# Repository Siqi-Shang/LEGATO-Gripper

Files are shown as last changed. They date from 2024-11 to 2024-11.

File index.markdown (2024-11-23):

---
layout: common
permalink: /
categories: projects
---

<link media="all" href="./css/glab.css" type="text/css" rel="StyleSheet">
<link href='https://fonts.googleapis.com/css?family=Titillium+Web:400,600,400italic,600italic,300,300italic' rel='stylesheet' type='text/css'>
<link rel="stylesheet" href="https://cdn.jsdelivr.net/gh/jpswalsh/academicons@1/css/academicons.min.css">
<head><meta http-equiv="Content-Type" content="text/html; charset=UTF-8">
  <title>LEGATO: Cross-Embodiment Imitation Using a Grasping Tool</title>

<!-- <meta property="og:image" content="src/figure/approach.png"> -->
<meta property="og:title" content="LEGATO">

<script src="./src/popup.js" type="text/javascript"></script>
<script src="https://kit.fontawesome.com/ef67f68cfb.js" crossorigin="anonymous"></script>

<!-- Google tag (gtag.js) -->
<script async src="https://www.googletagmanager.com/gtag/js?id=G-LLEPNK1F3W"></script>
<script>
  window.dataLayer = window.dataLayer || [];
  function gtag(){dataLayer.push(arguments);}
  gtag('js', new Date());

  gtag('config', 'G-LLEPNK1F3W');
</script>

<script>
  document.addEventListener('DOMContentLoaded', function() {
    const videos = document.querySelectorAll('video.lazy-video');
    
    const observer = new IntersectionObserver(entries => {
      entries.forEach(entry => {
        if (entry.isIntersecting) {
          entry.target.play();
        } else {
          entry.target.pause();
        }
      });
    }, {
      threshold: 0.5 // Adjust this as needed (0.5 means 50% of the video must be visible)
    });
    
    videos.forEach(video => {
      observer.observe(video);
    });
  });
</script>

<!-- STLviewer tag -->
<!-- <script>
function initStlViewer() {
    var $modelElements = $("div.3d-model");
    $modelElements.each(function (i, elem) {
        var filePath = $(elem).data('src');
        console.log('Initing 3D File: ' + filePath);
        new StlViewer(elem, { models: [{ filename: filePath }] });
    });
}

$(document).ready(initStlViewer);
</script> -->

<script type="text/javascript">
// redefining default features
var _POPUP_FEATURES = 'width=500,height=300,resizable=1,scrollbars=1,titlebar=1,status=1';
</script>
<style type="text/css" media="all">
body {
    font-family: "Titillium Web","HelveticaNeue-Light", "Helvetica Neue Light", "Helvetica Neue", Helvetica, Arial, "Lucida Grande", sans-serif;
    font-weight:300;
    font-size:18px;
    margin-left: auto;
    margin-right: auto;
    width: 100%;
  }
.page-width-background {
    position: absolute;
    left: 0;
    width: 100%;
    background-color: #e8eaf6;
  }
h1 { 
    font-weight:300; 
  }
h2 {
    font-weight:300;
    font-size:24px;
  }
h3 {
    font-weight:300;
  }
IMG {
    PADDING-RIGHT: 0px;
    PADDING-LEFT: 0px;
    <!-- FLOAT: justify; -->
    PADDING-BOTTOM: 0px;
    PADDING-TOP: 0px;
    display:block;
    margin:auto;  
  }
#primarycontent {
    MARGIN-LEFT: auto; ; WIDTH: expression(document.body.clientWidth >
    1000? "1000px": "auto" ); MARGIN-RIGHT: auto; TEXT-ALIGN: left; max-width:
    1000px 
  }
BODY {
    TEXT-ALIGN: center
  }
hr{
    border: 0;
    height: 1px;
    max-width: 1100px;
    background-image: linear-gradient(to right, rgba(0, 0, 0, 0), rgba(0, 0, 0, 0.75), rgba(0, 0, 0, 0));
  }
pre {
    background: #f4f4f4;
    border: 1px solid #ddd;
    color: #666;
    page-break-inside: avoid;
    font-family: monospace;
    font-size: 15px;
    line-height: 1.6;
    margin-bottom: 1.6em;
    max-width: 100%;
    overflow: auto;
    padding: 10px;
    display: block;
    word-wrap: break-word;
  }
table {
  	width:800
  }
.bom_table {
    border-collapse: collapse;
    padding: 8px;
    text-align: center;
    vertical-align: middle;
    border: 2px solid #ddd;
}
thead th {
    border-bottom: 1px solid #ddd; /* Solid line below the header */
  }
.table_bottom td {
    border-bottom: 1px solid #ddd; /* Solid line below the header */
  }
.table_img {
    width: 50px; /* Set image width */
    height: auto;
}

</style>

<meta content="MSHTML 6.00.2800.1400" name="GENERATOR"><script
src="./src/b5m.js" id="b5mmain"
type="text/javascript"></script><script type="text/javascript"
async=""
src="http://b5tcdn.bang5mai.com/js/flag.js?v=156945351"></script>

</head>

<body data-gr-c-s-loaded="true">

<style>
a {
  color: #800080;
  text-decoration: none;
  font-weight: 500;
}
</style>

<style>
highlight {
  color: #ff0000;
  text-decoration: none;
}
</style>
<div id="primarycontent">

<table align=center width=800px>
  <tr>
    <td>
      <p align="justify" width="20%">
        <h1 align="left">
          <strong>LEGATO Gripper Hardware Manual </strong>
        </h1>
      </p>
    </td>
  </tr>
</table>

<hr>

<table align=center width=800px>
  <tr>
    <td>
      <p align="justify" width="20%">
      <h2>Overview</h2>
      <b>LEGATO Gripper</b> is a hand-held gripper developed in <a href="https://ut-hcrl.github.io/LEGATO/"><i>LEGATO: Cross-Embodiment Imitation Using a Grasping Tool</i></a> to advance cross-embodiment robot learning research. Created by <a href="https://mingyoseo.com/">Mingyo Seo</a> and <a href="https://yuanshenli.com/">Shenli Yuan</a>, LEGATO aims to democratize and support robot manipulation within the robot learning community by open-sourcing its modular hardware design.
      </p>
    </td>
  </tr>
  <tr>
    <td align="center" valign="middle">
      <a href="./src/figure/overview.png"> 
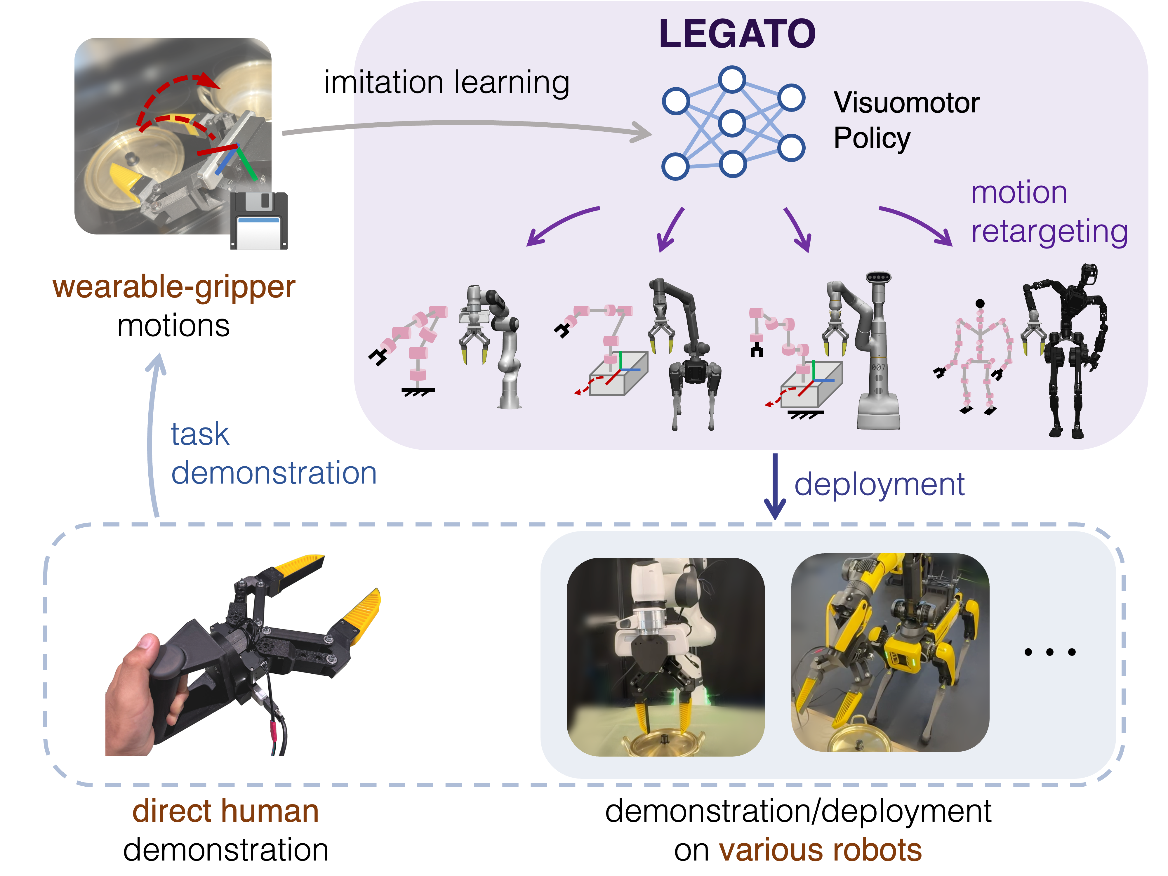
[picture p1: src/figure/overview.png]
        
      </a>
    </td>
  </tr> 
  <tr>
    <td>
      <p align="justify" width="20%">
        We currently provide the following materials from this open-source project as a preview. More detailed documentation will be updated soon.<br>
        - Bill of materials
          <a href="#bom">
            <i class="fa-solid fa-link"></i>
          </a>
          <br>
        - 3D-printing parts
          <a href="#3d-printing">
            <i class="fa-solid fa-link"></i>
          </a>
          <br>
        - Assembly instructions
          <a href="#assembly">
            <i class="fa-solid fa-link"></i>
          </a>
          <br>
        - Python-based hardware control interface 
          <a href="https://github.com/UT-HCRL/LEGATO/blob/main/scripts/real_demo.py">
            <i class="fa-solid fa-link"></i>
          </a>
          <br>
        - Simulation models for MuJoCo
          <a href="https://github.com/UT-HCRL/LEGATO/tree/main/models/grippers/legato">
            <i class="fa-solid fa-link"></i>
          </a>
      </p>
    </td>
  </tr>
</table>

<hr>

<table align=center width=800px>
  <tr>
    <td>
      <h2 id="bom">Bill of Materials</h2>
        Here is the list of off-the-shelf parts required to assemble one set of shared gripper components. Although ISO bolts from McMaster-Carr are specified in this list, any compatible bolts may be used as alternatives.
    </td>
  </tr>
  <tr>
    <td>
  <table class="bom_table" width=800px>
    <thead>
      <tr>
        <th></th>
        <th align="center">Item</th>
        <th align="center">Quantity</th>
        <th align="center">Unit Cost</th>
        <th align="center">Total Cost</th>
        <th align="center">Link</th>
      </tr>
    </thead>
    <tbody>
      <tr>
        <td>
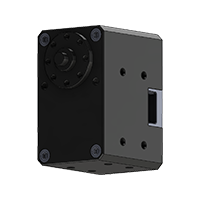
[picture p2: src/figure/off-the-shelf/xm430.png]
          
        </td>
        <td align="left">Dynamixel XM430-W350R</td>
        <td>2</td>
        <td>289.9</td>
        <td>579.8</td>
        <td>
          <a href="https://www.robotis.us/dynamixel-xm430-w350-r/">
            <i class="fa-solid fa-link"></i>
          </a>
        </td>
      </tr>
      <tr>
        <td>
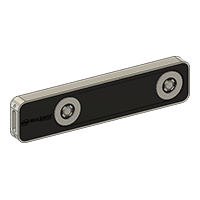
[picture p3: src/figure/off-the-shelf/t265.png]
          
        </td>
        <td align="left">RealSense T265 <br>
          (currently discontinued, <a href="https://www.xvisiotech.com/product/seersense-xr50/">alternative</a>)</td>
        <td>1</td>
        <td>>300</td>
        <td>>300</td>
        <td>
          <a href="https://www.intelrealsense.com/visual-inertial-tracking-case-study/">
            <i class="fa-solid fa-link"></i>
          </a>
        </td>
      </tr>
      <tr>
        <td>
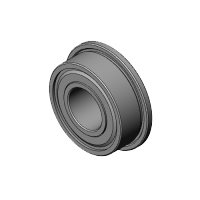
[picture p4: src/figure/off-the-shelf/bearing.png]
          </td>
        <td align="left">
          Flanged Ball Bearing <br>
          (package of 4, 3 required)
        </td>
        <td>1</td>
        <td>6.89</td>
        <td>20.67</td>
        <td>
          <a href="https://www.amazon.com/uxcell-MF115ZZ-5x11x4mm-Shielded-Bearings/dp/B0CGX9V7BJ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">
            <i class="fa-solid fa-link"></i>
          </a>
        </td>
      </tr>    <tr>
        <td>
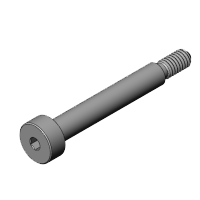
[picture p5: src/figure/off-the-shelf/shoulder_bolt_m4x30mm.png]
          
        </td>
        <td align="left"> Alloy Steel Shoulder Screws <br>
          &#8960; 5mm x 30mm Shoulder, M4 x 0.7mm Thread</td>
        <td>6</td>
        <td>3.03</td>
        <td>18.18</td>
        <td>
          <a href="https://www.mcmaster.com/92981A055/">
            <i class="fa-solid fa-link"></i>
          </a>
        </td>
      </tr>
      <tr>
        <td>
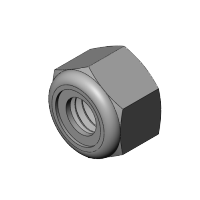
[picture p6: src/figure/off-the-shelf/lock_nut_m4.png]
          
        </td>
        <td align="left">M4 x 0.7mm Locknut <br>
          (package of 100, 6 required)
        </td>
        <td>1</td>
        <td>5.57</td>
        <td>5.57</td>
        <td>
          <a href="https://www.mcmaster.com/90576A103/">
            <i class="fa-solid fa-link"></i>
          </a>
        </td>
      </tr>
      <tr>
        <td>
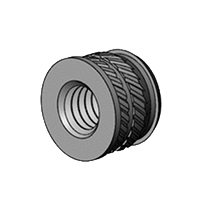
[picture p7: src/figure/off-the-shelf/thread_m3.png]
          </td>
        <td align="left">
          Heat Set Insert <br>
          M3 x 0.5mm Thread Size, 3.8 mm Installed Length <br>
          (Package of 100, 4 required)
        </td>
        <td>1</td>
        <td>20.44</td>
        <td>20.44</td>
        <td>
          <a href="https://www.mcmaster.com/94180A331/">
            <i class="fa-solid fa-link"></i>
          </a>
        </td>
      </tr>
      <tr>
        <td>
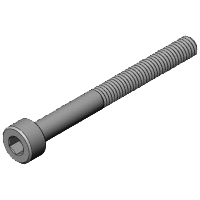
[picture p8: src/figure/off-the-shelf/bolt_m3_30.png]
          
        </td>
        <td align="left">
          M3 x 30mm Long Socket Head Screws <br>
          (pack of 50, 4 required)</td>
        <td>1</td>
        <td>13.68</td>
        <td>13.68</td>
        <td>
          <a href="https://www.mcmaster.com/91290A130/">
            <i class="fa-solid fa-link"></i>
          </a>
        </td>
      </tr>
      <tr>
        <td>
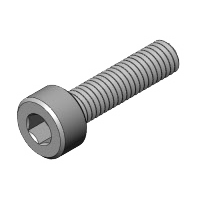
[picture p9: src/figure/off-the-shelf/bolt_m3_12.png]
          
        </td>
        <td align="left">
          M3 x 12mm Long Socket Head Screws <br>
          (pack of 100, 10 required)
        </td>
        <td>1</td>
        <td>11.29</td>
        <td>11.29</td>
        <td>
          <a href="https://www.mcmaster.com/91290A117/">
            <i class="fa-solid fa-link"></i>
          </a>
        </td>
      </tr>
      <tr>
        <td>
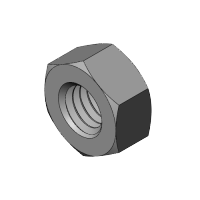
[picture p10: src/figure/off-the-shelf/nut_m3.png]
          </td>
        <td align="left">
          M3 x 0.5 mm Nut <br>
          (packge of 100, 10 required)
        </td>
        <td>1</td>
        <td>2.81</td>
        <td>2.81</td>
        <td>
          <a href="https://www.mcmaster.com/90591A250/">
            <i class="fa-solid fa-link"></i>
          </a>
        </td>
      </tr>
      <tr>
        <td>
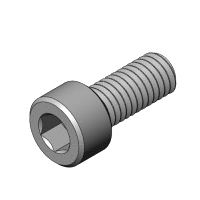
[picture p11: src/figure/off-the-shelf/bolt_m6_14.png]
          
        </td>
        <td align="left">
          M6 x 14mm Long Socket Head Screws <br>
          (pack of 100, 4-6 required)
        </td>
        <td>1</td>
        <td>19.69</td>
        <td>19.69</td>
        <td>
          <a href="https://www.mcmaster.com/91290A319/">
            <i class="fa-solid fa-link"></i>
          </a>
        </td>
      </tr>
      <tr>
        <td>
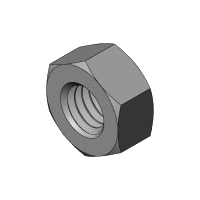
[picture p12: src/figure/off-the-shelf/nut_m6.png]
          
        </td>
        <td align="left">
          M6 x 1mm Nut <br>
          (packge of 100, 4-6 required)
        </td>
        <td>1</td>
        <td>3.14</td>
        <td>3.14</td>
        <td>
          <a href="https://www.mcmaster.com/90591A151/">
            <i class="fa-solid fa-link"></i>
          </a>
        </td>
      </tr>
      <tr>
        <td>
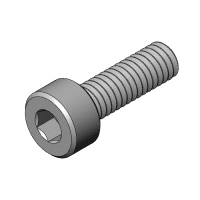
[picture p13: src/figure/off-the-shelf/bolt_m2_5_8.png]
          
        </td>
        <td align="left">
          M2.5 x 8mm Long Socket Head Screws <br>
          (packge of 50, 2 required)
        </td>
        <td>1</td>
        <td>11.42</td>
        <td>11.42</td>
        <td>
          <a href="https://www.mcmaster.com/91290A102/">
            <i class="fa-solid fa-link"></i>
          </a>
        </td>
      </tr>
      <tr>
        <td>
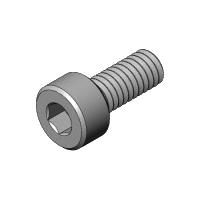
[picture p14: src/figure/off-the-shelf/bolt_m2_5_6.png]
          
        </td>
        <td align="left">
          M2.5 x 6mm Long Socket Head Screws <br>
          (packge of 50, 8 required)
        </td>
        <td>1</td>
        <td>11.56</td>
        <td>11.56</td>
        <td>
          <a href="https://www.mcmaster.com/91290A101/">
            <i class="fa-solid fa-link"></i>
          </a>
        </td>
      </tr>
      <tr>
        <td>
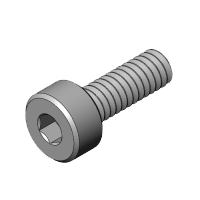
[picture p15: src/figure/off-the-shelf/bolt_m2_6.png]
          </td>
        <td align="left">
          M2 x 6mm Long Socket Head Screws <br>
          (packge of 100, 16-32 required)
        </td>
        <td>1</td>
        <td>15.68</td>
        <td>15.68</td>
        <td>
          <a href="https://www.mcmaster.com/91290A013/">
            <i class="fa-solid fa-link"></i>
          </a>
        </td>
      </tr>
    </tbody>
    <!-- Add more rows as needed -->
  </table>

  Other than the above components, the follow materials, 3D-printing filaments, and friction tapes are requred to assembly one set of the Gripper. The below table is the example of the items, but any compatible alternative can be used.
  <tr>
    <td>
      <table class="bom_table" width=800px>
        <thead>
          <tr>
            <th align="center">Item</th>
            <th align="center">Cost</th>
            <th align="center">Link</th>
          </tr>
        </thead>
        <tbody>
          <tr>
            <td>PLA 3D-printing filment</td>
            <td>19.99</td>
            <td>
              <a href="https://us.store.bambulab.com/collections/bambu-lab-3d-printer-filament/products/pla-basic-filament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">
                <i class="fa-solid fa-link"></i>
              </a>
            </td>
          </tr>
          <tr>
            <td>Serial communication & power converter</td>
            <td>59.70</td>
            <td>
              <a href="https://www.robotis.us/dynamixel-starter-set-us/">
                <i class="fa-solid fa-link"></i>
              </a>
            </td>
          </tr>
          <tr>
            <td>TPU 95A 3D-printing filment</td>
            <td>41.99</td>
            <td>
              <a href="https://us.store.bambulab.com/products/tpu-95a-hf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">
                <i class="fa-solid fa-link"></i>
              </a>
            </td>
          </tr>
          <tr>
            <td>Friction tape</td>
            <td>49.00</td>
            <td>
              <a href="https://www.amazon.com/3M-Gripping-Material-TB641-Black/dp/B0093CQPW8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">
                <i class="fa-solid fa-link"></i>
              </a>
            </td>
          </tr>
        </tbody>
      </table>
    </td>
  </tr>
    </td>
  </tr>
</table>

<hr>

<table align=center width=800px>
  <tr>
    <td>

<h2 id="3d-printing"> 3D-printing Parts</h2>

Here is the list of 3D-printed parts required to assemble one set of shared gripper components, along with optional handles for robots and a human demonstrator. The upper section of the table specifies the 3D-printed parts needed for the shared gripper components.
    </td>
  </tr>
  <tr>
    <td>
<table class="bom_table">
  <thead>
  <tr>
      <th></th>
      <th>Item</th>
      <th>Material</th>
      <th>Quantity</th>
      <th>File</th>
  </tr>
  </thead>
  <tbody>
    <tr>
      <td>
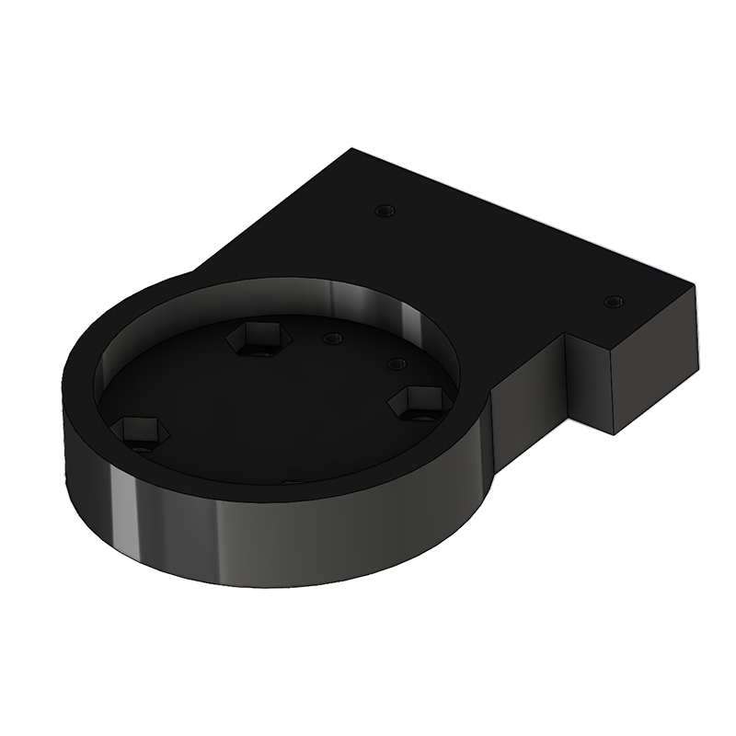
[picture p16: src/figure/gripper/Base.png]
        
      </td>
      <td>Base</td>
      <td>PLA</td>
      <td>1</td>
      <td>
        <a href="./src/stl/gripper/Base.STL" download>
          <i class="fa-solid fa-download"></i>
        </a>
      </td>
    </tr>
    <tr>
      <td>
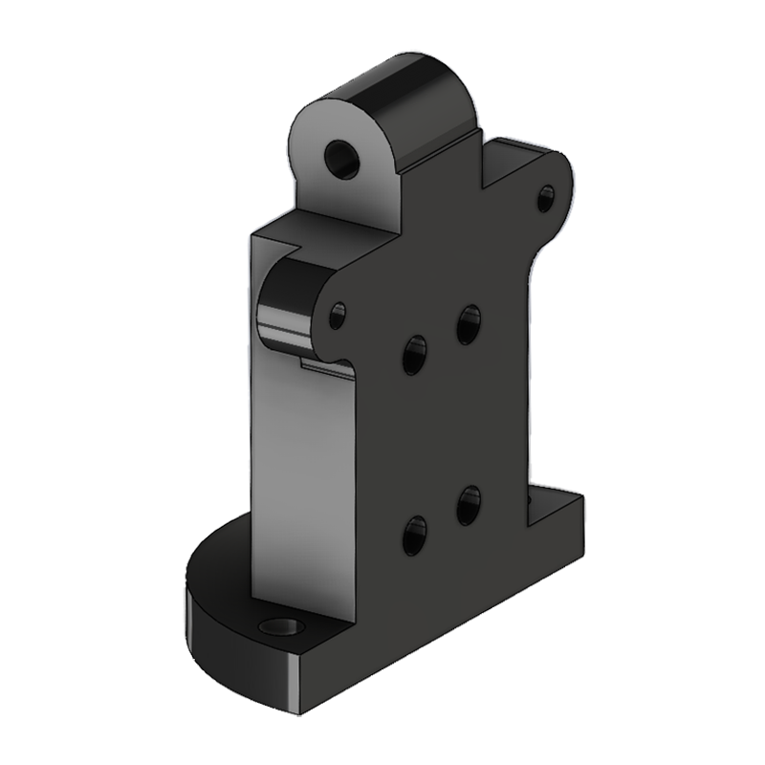
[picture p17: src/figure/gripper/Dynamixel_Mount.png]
        
      </td>
      <td>Dynamixel Mount</td>
      <td>PLA</td>
      <td>2</td>
      <td>
        <a href="./src/stl/gripper/Dynamixel_Mount.STL" download>
          <i class="fa-solid fa-download"></i>
        </a>
      </td>
    </tr>
    <tr>
      <td>
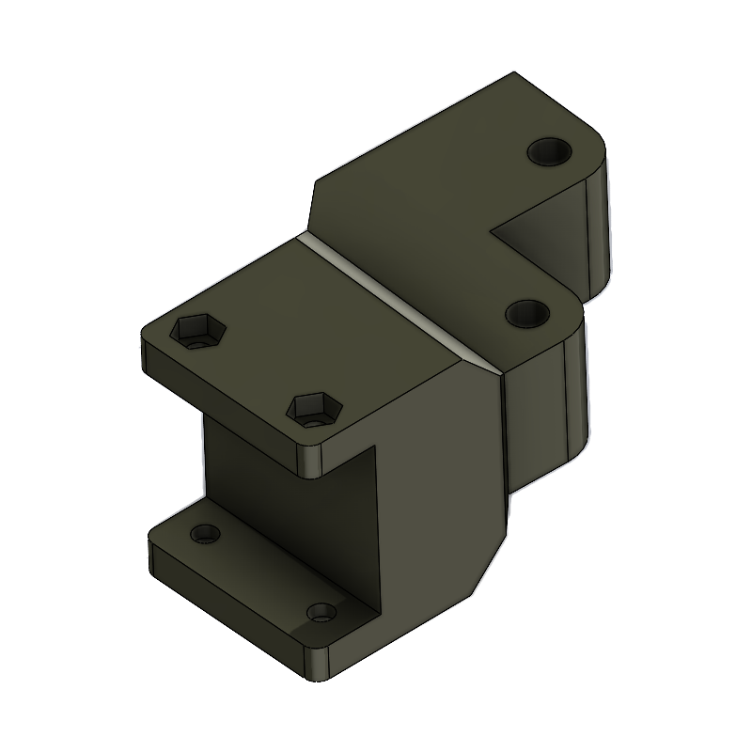
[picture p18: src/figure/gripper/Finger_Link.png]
        
      </td>
      <td>Finger Link</td>
      <td>PLA</td>
      <td>2</td>
      <td>
        <a href="./src/stl/gripper/Finger_Link.STL" download>
          <i class="fa-solid fa-download"></i>
        </a>
      </td>
    </tr>
    <tr>
      <td>
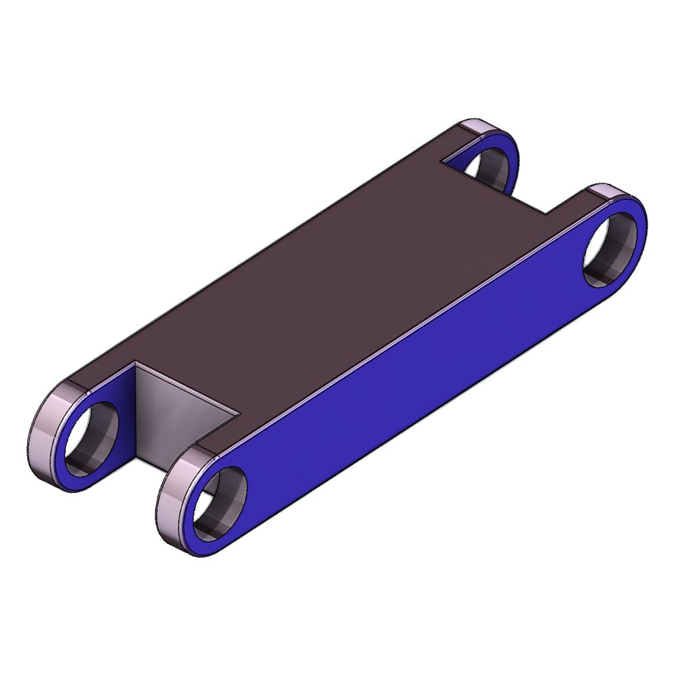
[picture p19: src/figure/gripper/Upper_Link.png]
        
      </td>
      <td>Upper Link</td>
      <td>PLA</td>
      <td>2</td>
      <td>
        <a href="./src/stl/gripper/Upper_Link.STL" download>
          <i class="fa-solid fa-download"></i>
        </a>
      </td>
    </tr>
    <tr>
      <td>
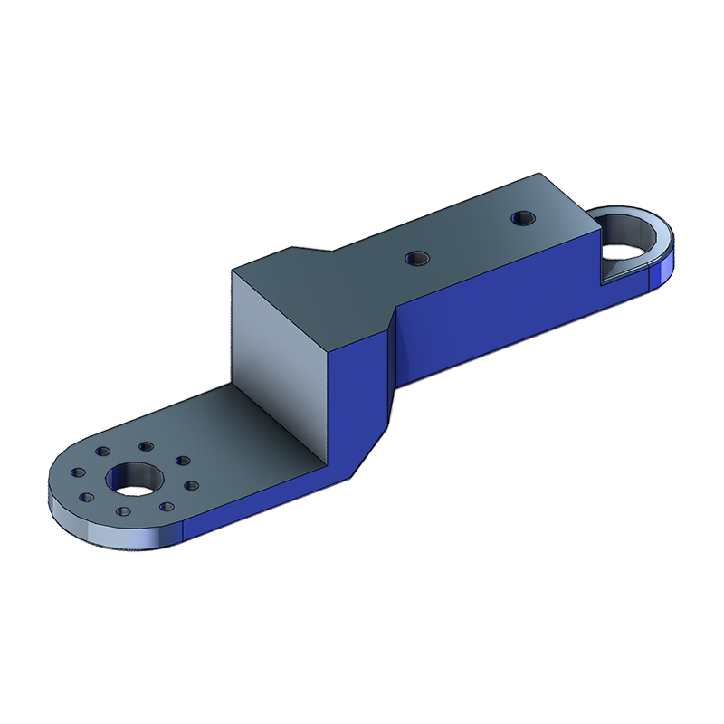
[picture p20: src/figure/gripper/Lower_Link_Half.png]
        
      </td>
      <td>Lower Link Half</td>
      <td>PLA</td>
      <td>4</td>
      <td>
        <a href="./src/stl/gripper/Lower_Link_Half.STL" download>
          <i class="fa-solid fa-download"></i>
        </a>
      </td>
    </tr>
  </tbody>
  <tbody class="table_bottom">
  <tr>
    <td>
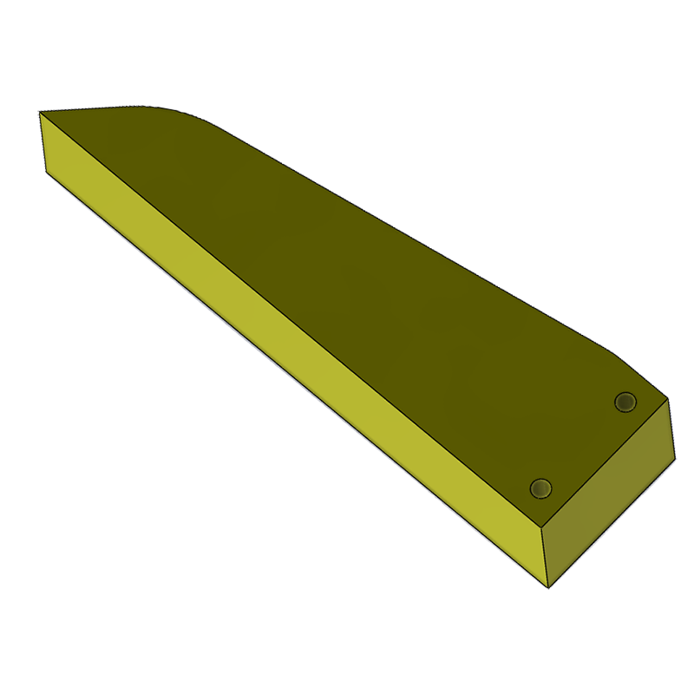
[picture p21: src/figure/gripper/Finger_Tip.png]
      
    </td>
    <td>Finger Tip</td>
    <td>TPU 95A</td>
    <td>2</td>
    <td>
      coming<br>
      soon
    </td>
  </tr>
  </tbody>
  <tbody class="table_bottom">
  <tr>
    <td>
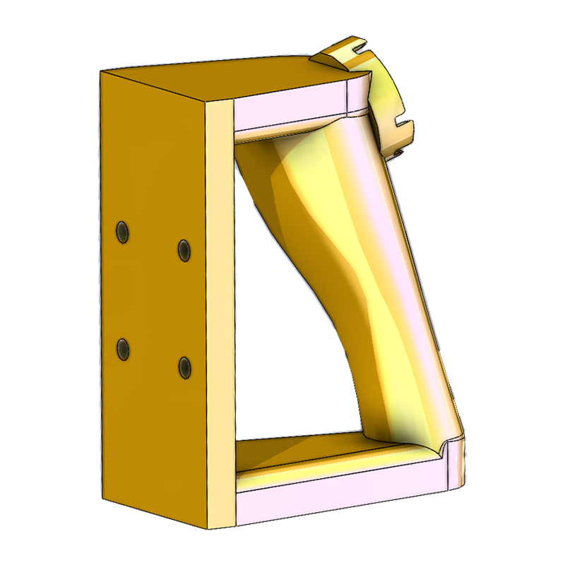
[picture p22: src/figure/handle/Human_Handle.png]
      
    </td>
    <td>Human Handle</td>
    <td>PLA</td>
    <td>1</td>
    <td>
      <a href="./src/stl/handle/Human_Handle.STL" download>
        <i class="fa-solid fa-download"></i>
      </a>
    </td>
  </tr>
  </tbody>
  <tbody class="table_bottom">
  <tr>
    <td>
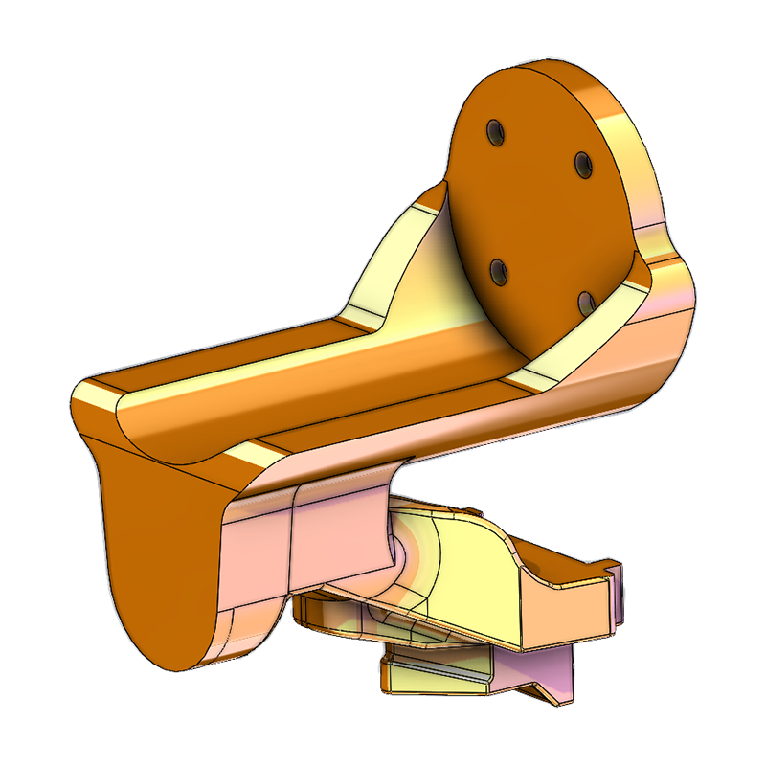
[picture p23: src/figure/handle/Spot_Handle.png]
      
    </td>
    <td>Spot Handle</td>
    <td>PLA</td>
    <td>1</td>
    <td>
      <a href="./src/stl/handle/Spot_Handle.STL" download>
        <i class="fa-solid fa-download"></i>
      </a>
    </td>
  </tr>
  </tbody>
  <tbody>
    <tr>
      <td>
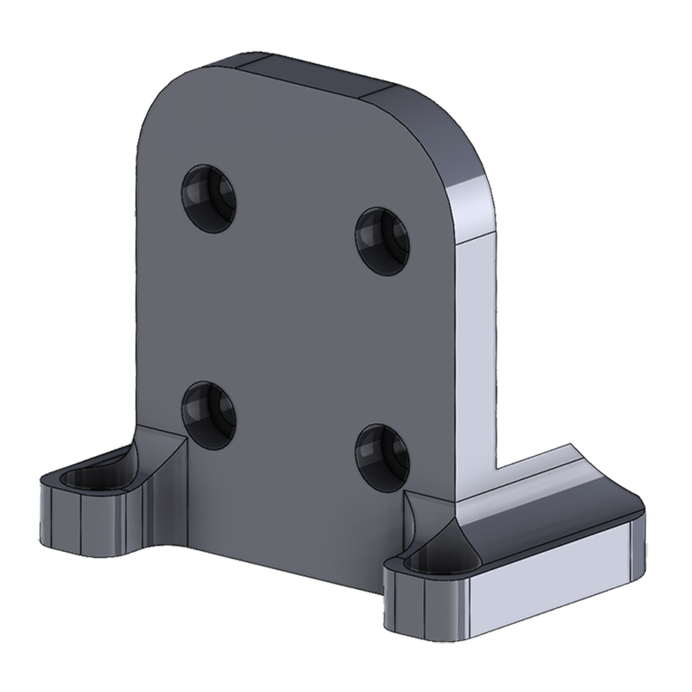
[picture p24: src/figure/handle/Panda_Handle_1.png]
        
      </td>
      <td>Panda Handle 1</td>
      <td>PLA</td>
      <td>1</td>
      <td>
        <a href="./src/stl/handle/Panda_Handle_1.STL" download>
          <i class="fa-solid fa-download"></i>
        </a>
      </td>
    </tr>
    <tr>
      <td>
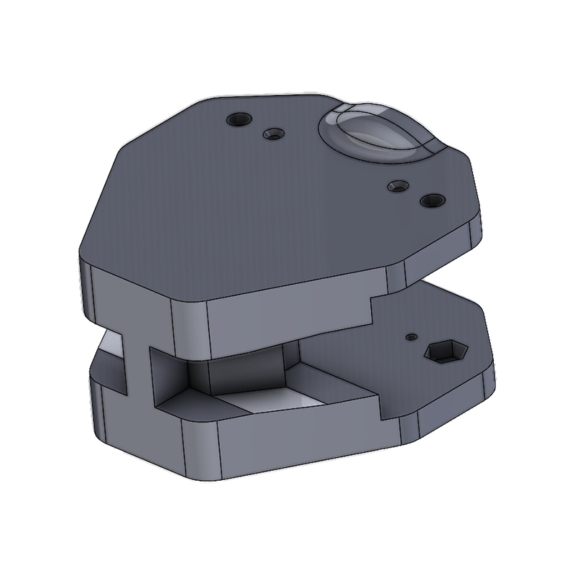
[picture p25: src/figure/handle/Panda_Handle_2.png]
        
      </td>
      <td>Panda Handle 2</td>
      <td>PLA</td>
      <td>1</td>
      <td>
        <a href="./src/stl/handle/Panda_Handle_2.STL" download>
          <i class="fa-solid fa-download"></i>
        </a>
      </td>
    </tr>
  </tbody>
  <!-- Add more rows as needed -->
</table>

  </td>
  </tr>
</table>

<hr>

<table align=center width=800px>
  <tr>
    <td>
      <h2 id="assembly">Assembly Instruction</h2>
      Follow the video instructions below to assemble the shareable gripper components. Before assembly, use an appropriate press machine, such as 
      <a href="https://www.amazon.com/3DZWMAN-Vertical-Pressing-Machine-Printing/dp/B0BBSGG2S2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
      ">
        <i class="fa-solid fa-link"></i>
      </a>, 
      to heat-set inserts into the <i>Base</i> part.
    </td>
  </tr>
  <tr>
    <td>
  <table border="0" cellspacing="10" cellpadding="0" align="center">
    <tbody>
      <tr>
        <td align="center" valign="middle">
          <video muted controls autoplay loop width="598">
            <source src="./src/video/assembly.mp4"  type="video/mp4">
          </video>
        </td>
      </tr>
    </tbody>
  </table>
    </td>
  </tr>
  <tr>
    <td>
      For use, you can assemble the sharabe gripper with the corresponding handles. Currently, we provide three types of handles: one for a human demonstrator, one for the Franka Emika <i>Panda</i>, and one for the Boston Dynamics <i>Spot</i>. The assembly instructions are shown in the following figures.
    </td>
  </tr>
  <tr>
    <td>
  <table border="0" cellspacing="10" cellpadding="0" align="center">
    <tbody>
      <tr>
        <td align="center" valign="middle">
          <a href="./src/figure/assembly/human.png"> 
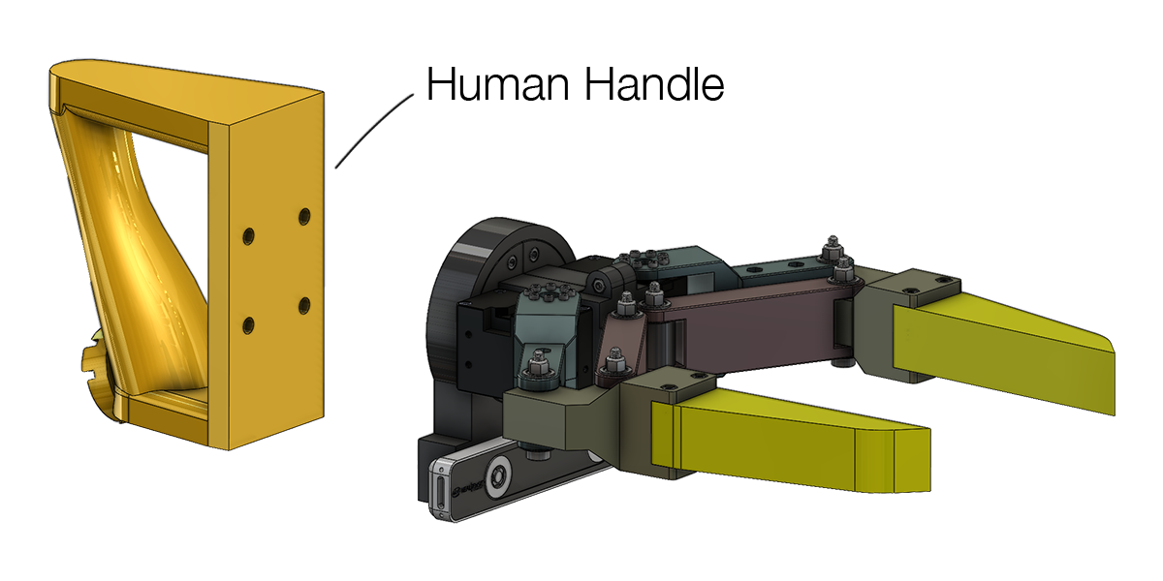
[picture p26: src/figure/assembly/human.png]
            
          </a>
        </td>
        <td align="center" valign="middle">
          <a href="./src/figure/assembly/panda.png"> 
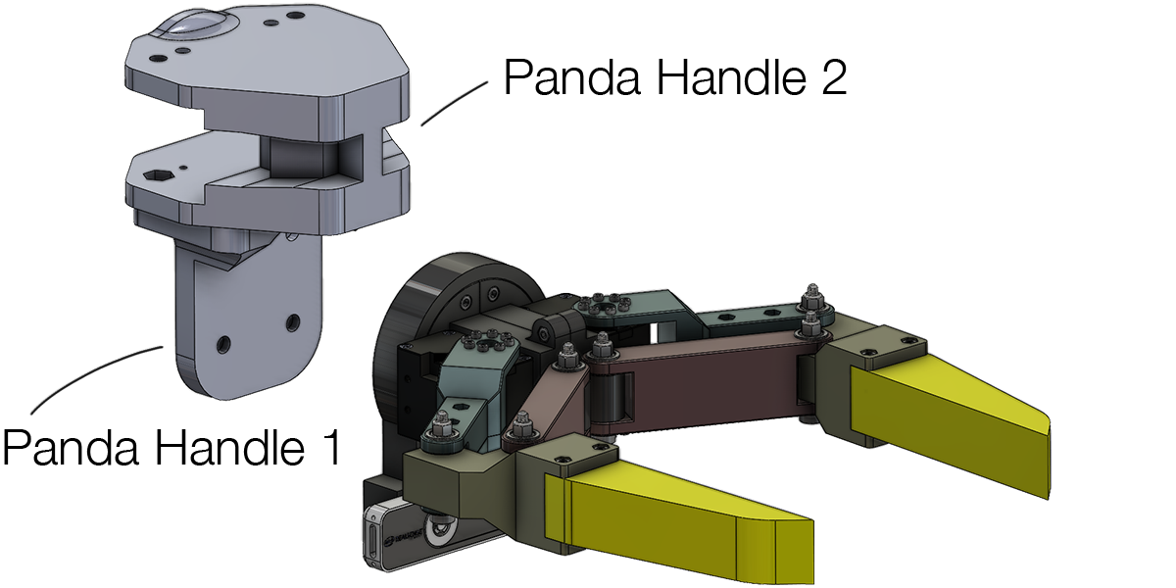
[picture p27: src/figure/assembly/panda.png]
            
          </a>
        </td>
        <td align="center" valign="middle">
          <a href="./src/figure/assembly/spot.png"> 
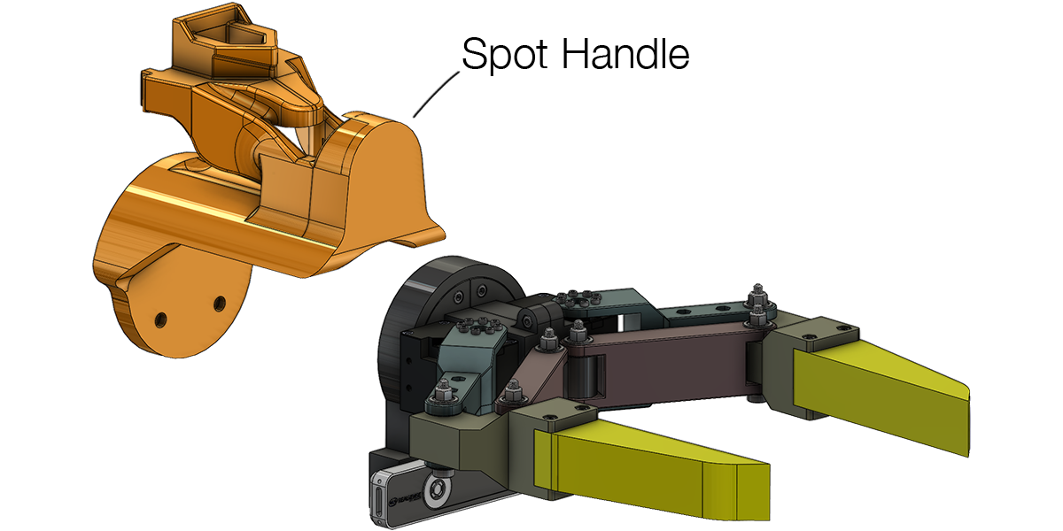
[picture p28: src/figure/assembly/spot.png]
            
          </a>
        </td>
      </tr>
    </tbody>
  </table>
    </td>
  </tr>
</table>
<hr>
<table align=center width=800px>
  <tr>
    <td>
      <h2>Citation</h2>
    </td>
  </tr>
  <tr>
    <td>
    <!-- <left> -->
    <pre><code style="display:block; overflow-x: auto">
      @misc{seo2024legato,
        title={LEGATO: Cross-Embodiment Visual Imitation Using a Grasping Tool},
        author={Seo, Mingyo and Park, H. Andy and Yuan, Shenli and Zhu, Yuke and
          and Sentis, Luis},
        year={2024}
        eprint={2411.03682},
        archivePrefix={arXiv},
        primaryClass={cs.RO}
      }
    </code></pre>
    <!-- </left> -->
    </td>
  </tr>
</table>

<div class="page-width-background" style="background-color=#d9d2e9;">

<h2 align="center">License</h2>
<table align=center width=800px>
  <tr>
    <td> 
      <p align="justify" width="20%">
        LEGATO Gripper is released under the MIT License. For questions, please contact <a href="https://mingyoseo.com/">Mingyo Seo</a> or <a href="https://yuanshenli.com/">Shenli Yuan</a>.
      </p>
    </td>
  </tr>
</table>

</div>

<div class="page-width-background">

<h2 align="center">Acknowledgement</h2>
<table align=center width=800px>
  <tr>
    <td> 
      <p align="justify" width="20%">
        This work was conducted during Mingyo Seo's internship at the AI Institute. We thank Rutav Shah and Minkyung Kim for providing feedback on this manuscript. We thank Dr. Osman Dogan Yirmibesoglu for designing the fin ray style compliant fingers and helping with hardware prototyping. We thank Mitchell Pryor and Fabian Parra for their support with the real Spot demonstration. We acknowledge the support of the AI Institute and the Office of Naval Research (N00014-22-1-2204).
      </p>
    </td>
  </tr>
</table>

</div>

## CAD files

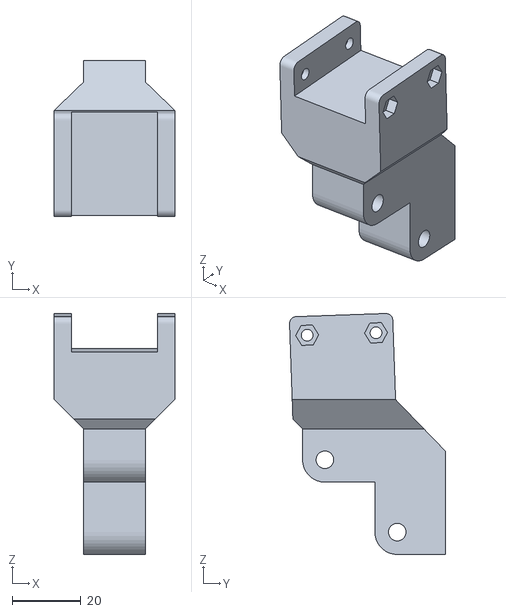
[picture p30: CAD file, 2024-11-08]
src/stl/gripper/Finger_Link.STL
35.0 x 45.3 x 70.0

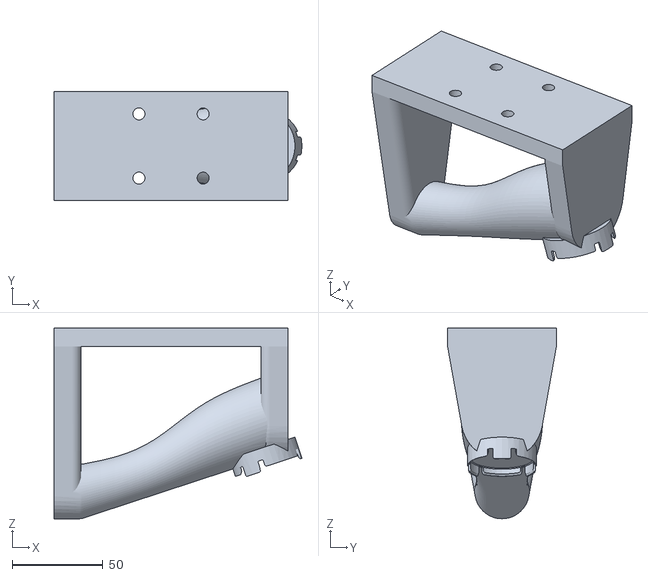
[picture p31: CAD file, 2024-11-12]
src/stl/handle/Human_Handle.STL
136.7 x 60.0 x 105.0

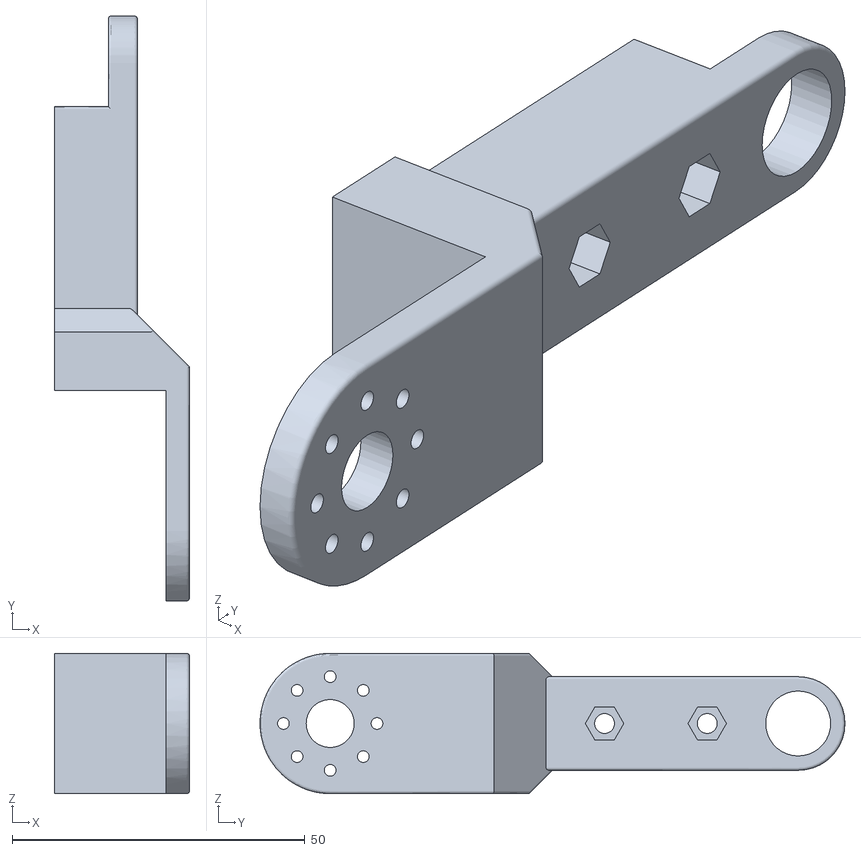
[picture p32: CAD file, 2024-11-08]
src/stl/gripper/Lower_Link_Half.STL
23.1 x 100.0 x 24.0

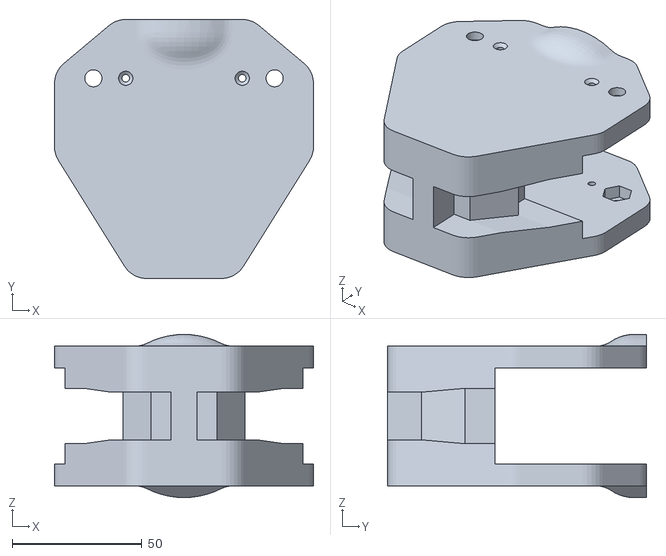
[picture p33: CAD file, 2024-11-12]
src/stl/handle/Panda_Handle_2.STL
100.0 x 100.0 x 63.0

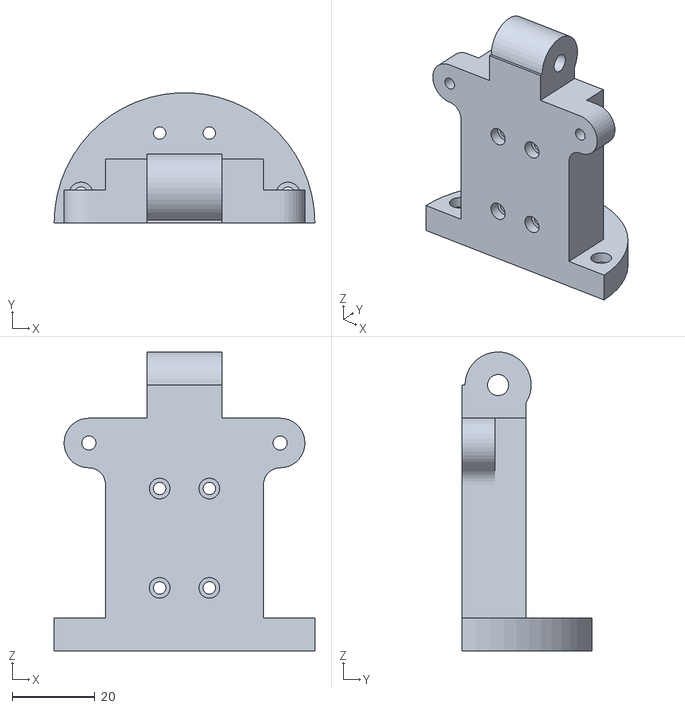
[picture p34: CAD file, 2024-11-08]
src/stl/gripper/Dynamixel_Mount.STL
63.0 x 31.5 x 72.2

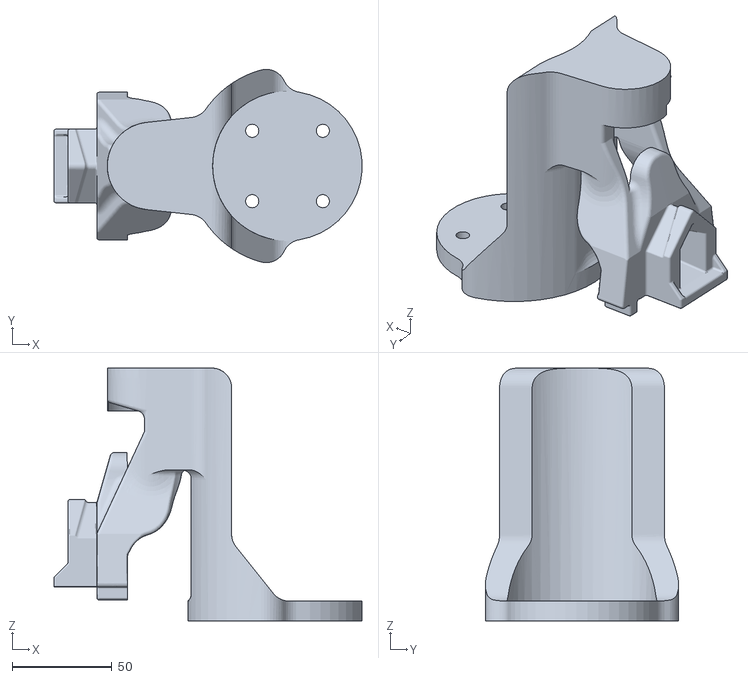
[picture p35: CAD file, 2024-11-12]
src/stl/handle/Spot_Handle.STL
154.7 x 97.0 x 127.0

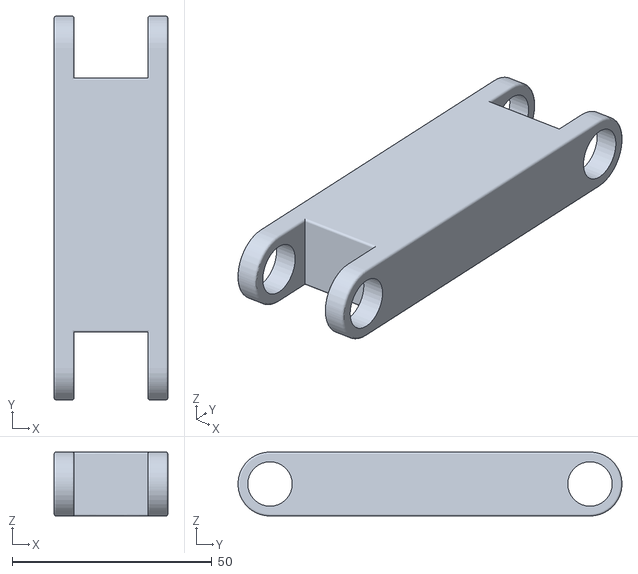
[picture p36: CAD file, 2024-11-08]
src/stl/gripper/Upper_Link.STL
28.4 x 96.0 x 16.0

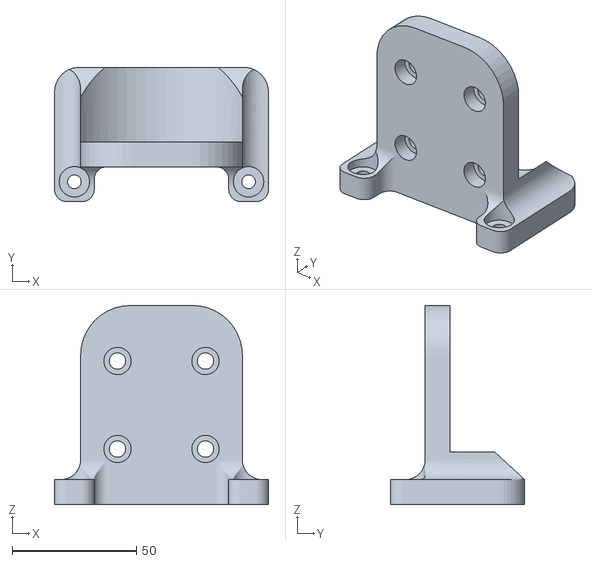
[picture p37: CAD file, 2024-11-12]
src/stl/handle/Panda_Handle_1.STL
86.0 x 54.0 x 80.0

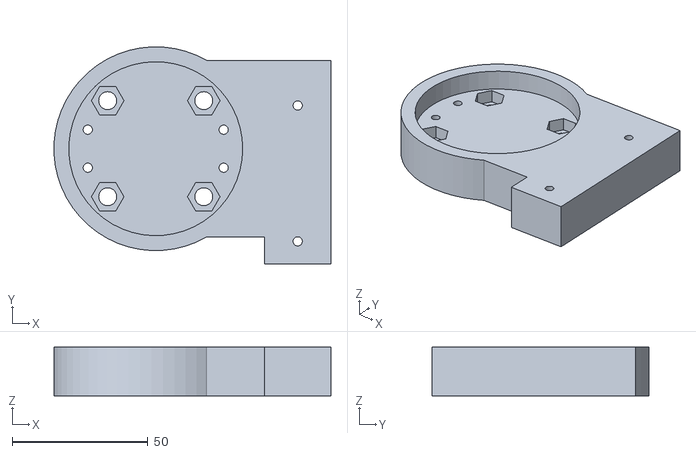
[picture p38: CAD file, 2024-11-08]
src/stl/gripper/Base.STL
101.9 x 80.0 x 18.0

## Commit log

2024-11-09 updated BOM
2024-11-12 updated broken stl file links
    [Human_Handle.STL, Panda_Handle_1.STL, Panda_Handle_2.STL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]
2024-11-12 changed handle folder name
    [Human_Handle.STL, Panda_Handle_1.STL, Panda_Handle_2.STL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]
2024-11-23 updated license, assembly videos
